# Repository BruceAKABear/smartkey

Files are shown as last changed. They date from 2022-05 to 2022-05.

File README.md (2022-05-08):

# smartkey-hardware

## 智能家居-智能开关

智能开关硬件设计使用kicad进行设计，gerber中已经包含可以直接打板的zip包，如果想去打板，直接将zip包发送至嘉立创打板即可。

智能开关pcb预览图为：



### 硬件设计特性

1. 智能开关硬件尺寸为：L:60mm,W:40mm，可以直接放置在实体开关的暗盒中
2. 提供两路输入控制
3. 对外提供adc和单独一路gpio以及+5V,方便扩展其他硬件

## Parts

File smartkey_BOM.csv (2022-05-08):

Comment | Description | Designator | Footprint | LibRef | Pins | Quantity | PartNumber | url
1uf | desc | C3,C2,C1, | C_0603_1608Metric | libref | 2 | 3
1N4148 | desc | D1,D3,D2, | D_0603_1608Metric | libref | 2 | 3
LED | desc | D4, | LED_0603_1608Metric | libref | 2 | 1
SS8050-G | desc | Q1,Q3,Q2, | SOT-23 | libref | 3 | 3
10k | desc | R6,R5,R4,R3,R2,R1, | R_0603_1608Metric | libref | 2 | 6
1k | desc | R7,R10,R9, | R_0603_1608Metric | libref | 2 | 3
SW_Push | desc | SW1, | bt-342 | libref | 2 | 1
ESP-07S | desc | U1, | ESP-07S | libref | 16 | 1
AMS1117-3.3 | desc | U3, | SOT-223-3_TabPin2 | libref | 4 | 1
Through Hole Items
Conn_01x02_Female | desc | J1, | TerminalBlock_bornier-2_P5.08mm | libref | 2 | 1
Conn_01x04_Female | desc | J2, | TerminalBlock_bornier-4_P5.08mm | libref | 4 | 1
Conn_01x06_Female | desc | J4, | PinHeader_1x06_P2.00mm_Vertical | libref | 6 | 1
CONN-4-conn-4 | desc | J6, | TerminalBlock_bornier-4_P5.08mm | libref | 4 | 1
G5LE-1 | desc | K1,K3,K2, | Relay_SPDT_Omron-G5LE-1 | libref | 5 | 3
rpdzv-5v | desc | U2, | rpdzn-5v | libref | 7 | 1

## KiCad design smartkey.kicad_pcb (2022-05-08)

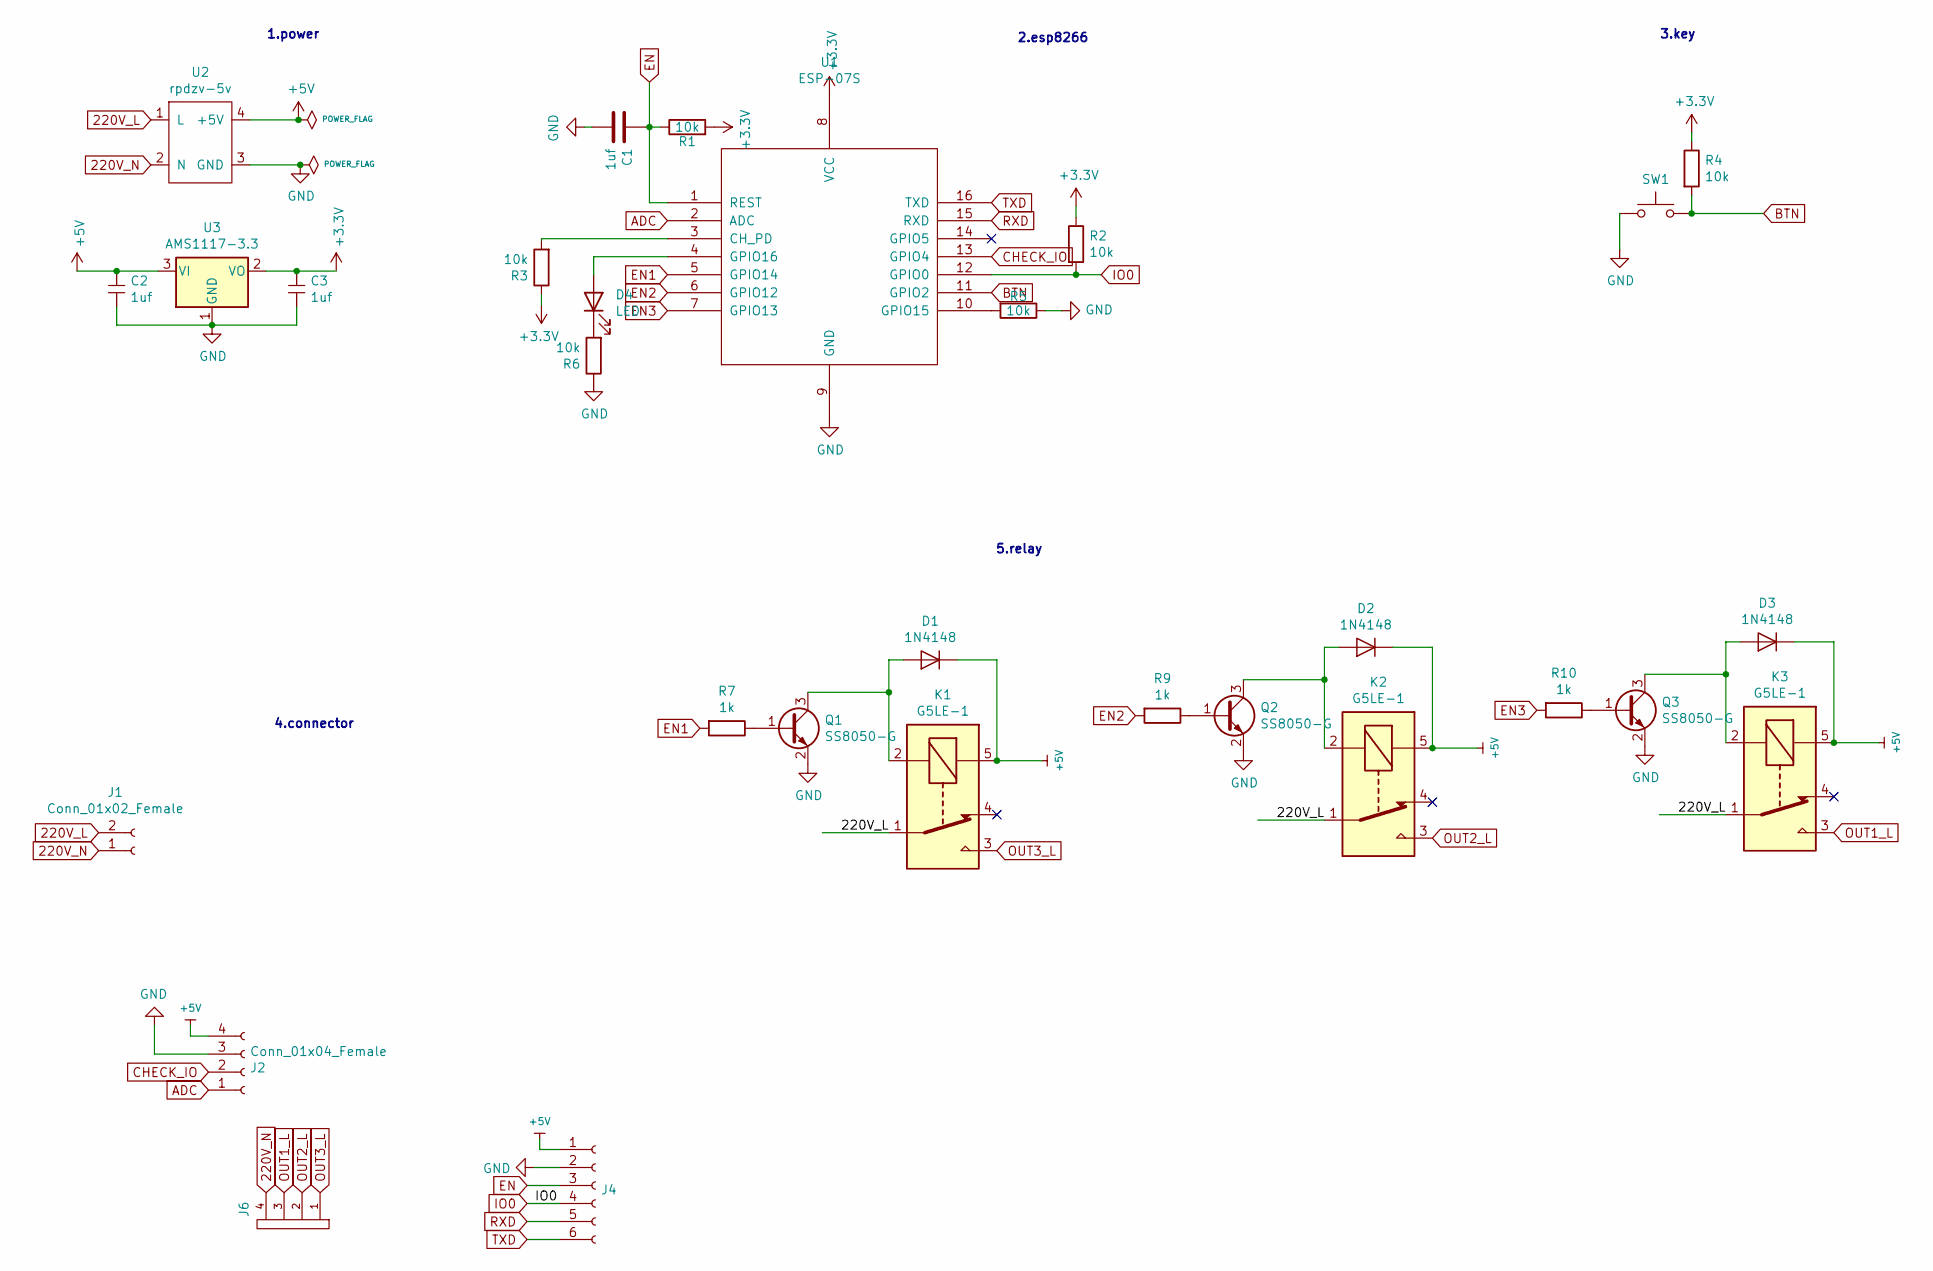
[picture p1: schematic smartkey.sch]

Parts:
C1, C2, C3: 1uf; C_0603_1608Metric
D1, D2, D3: 1N4148; D_0603_1608Metric
D4: LED; LED_0603_1608Metric
J1: Conn_01x02_Female; TerminalBlock_bornier-2_P5.08mm
J2: Conn_01x04_Female; TerminalBlock_bornier-4_P5.08mm
J4: Conn_01x06_Female; PinHeader_1x06_P2.00mm_Vertical
J6: CONN-4-conn-4; TerminalBlock_bornier-4_P5.08mm
K1, K2, K3: G5LE-1; Relay_SPDT_Omron-G5LE-1
Q1, Q2, Q3: SS8050-G; SOT-23
R1, R2, R3, R4, R5, R6: 10k; R_0603_1608Metric
R7, R9, R10: 1k; R_0603_1608Metric
SW1: SW_Push; bt-342
U1: ESP-07S
U2: rpdzv-5v; rpdzn-5v
U3: AMS1117-3.3; SOT-223-3_TabPin2

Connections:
220V_L: J1.2, K1.1, K2.1, K3.1, U2.1 (L)
220V_N: J1.1, J6.4, U2.2 (N)
+3V3: C3.1, R1.2, R2.1, R3.1, R4.1, U1.8 (VCC), U3.2 (VO)
ADC: J2.1, U1.2 (ADC)
BTN: R4.2, SW1.2, U1.11 (GPIO2)
CHECK_IO: J2.2, U1.13 (GPIO4)
EN: C1.1, J4.3, R1.1, U1.1 (REST)
EN1: R7.2, U1.5 (GPIO14)
EN2: R9.2, U1.6 (GPIO12)
EN3: R10.2, U1.7 (GPIO13)
IO0: J4.4, R2.2, U1.12 (GPIO0)
unnamed: D1.2 (A), K1.2, Q1.3 (C)
unnamed: D2.2 (A), K2.2, Q2.3 (C)
unnamed: D3.2 (A), K3.2, Q3.3 (C)
unnamed: D4.1 (K), R6.2
unnamed: D4.2 (A), U1.4 (GPIO16)
unnamed: Q1.1 (B), R7.1
unnamed: Q2.1 (B), R9.1
unnamed: Q3.1 (B), R10.1
unnamed: R3.2, U1.3 (CH_PD)
unnamed: R5.2, U1.10 (GPIO15)
OUT1_L: J6.3, K3.3
OUT2_L: J6.2, K2.3
OUT3_L: J6.1, K1.3
RXD: J4.5, U1.15 (RXD)
TXD: J4.6, U1.16 (TXD)

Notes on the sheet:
1.power
2.esp8266
3.key
5.relay
4.connector

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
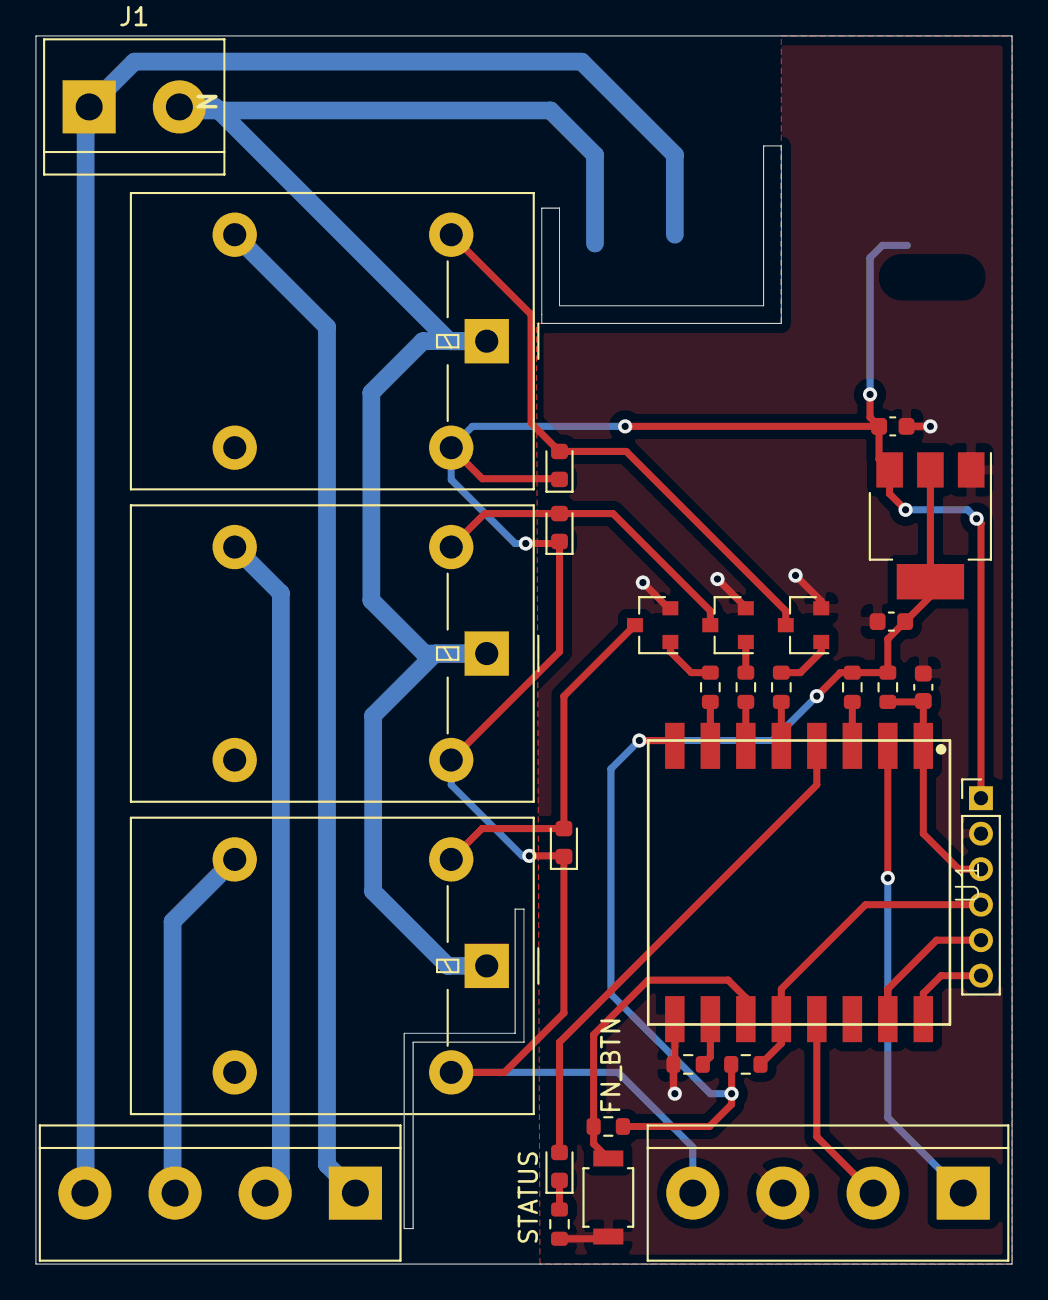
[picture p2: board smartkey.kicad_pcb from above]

Board: 2 copper layers, 55.0 x 69.2 mm, 30 parts (1 on the bottom side), 28 nets.
